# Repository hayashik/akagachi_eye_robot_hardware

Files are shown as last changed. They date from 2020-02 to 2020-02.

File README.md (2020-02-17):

# CAD data for DIY Akagachi
This data to develop your own Akagachi eye component.
3D printable data and 3D cad data are available. Software details are [here](https://github.com/hayashik/akagachi_eye_robot_ros).
There are follow two modes.  

## Akagachi type1 mode A
- Merit : Compact, easy to modify
- Demerit : Brush servo moters that connected directly will lower the robustness

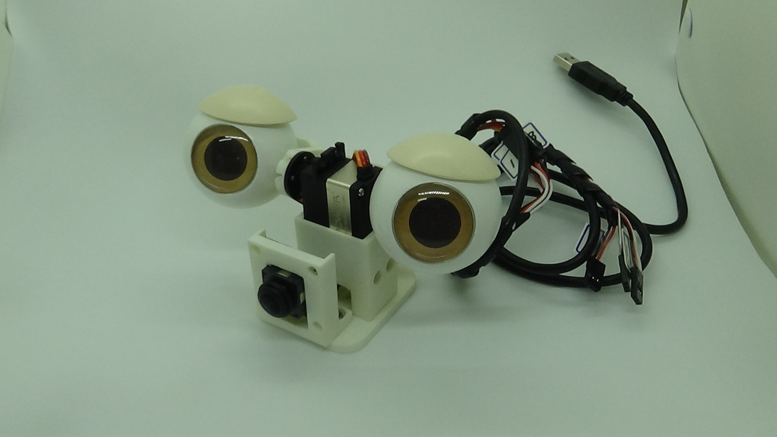
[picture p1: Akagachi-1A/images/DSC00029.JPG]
Overview1-A


## Akagachi type1 mode B
**2B is in preparation.**  
This data to develop your own Akagachi eye component.  
Type-1 is a small one (eye siza: 30mm) and a compact mode.
- Merit : Compact, easy to modify
- Demerit : Brushkess servo moters that connected by linkage will higher the robustness

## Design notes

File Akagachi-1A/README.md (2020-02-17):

CAD data for DIY Akagachi type1 mode A
====
## Overview  

This data to develop your own Akagachi eye component.  
Type-1 is a small one (eye siza: 30mm) and a compact mode.
- Merit : Compact, easy to modify
- Demerit : Brush servo moters that connected directly will lower the robustness
3D printable data and 3D cad data are available.

|Overviews||  
|:---|:---|
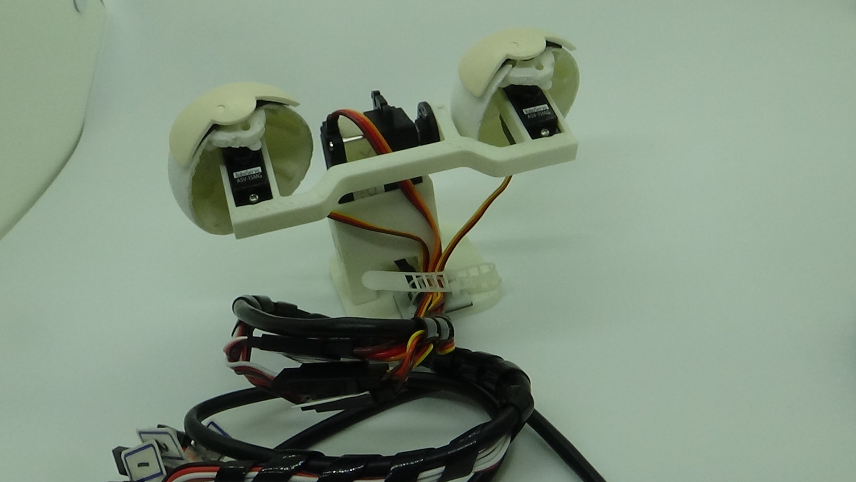
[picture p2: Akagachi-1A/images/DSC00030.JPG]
Back
|Overview||  
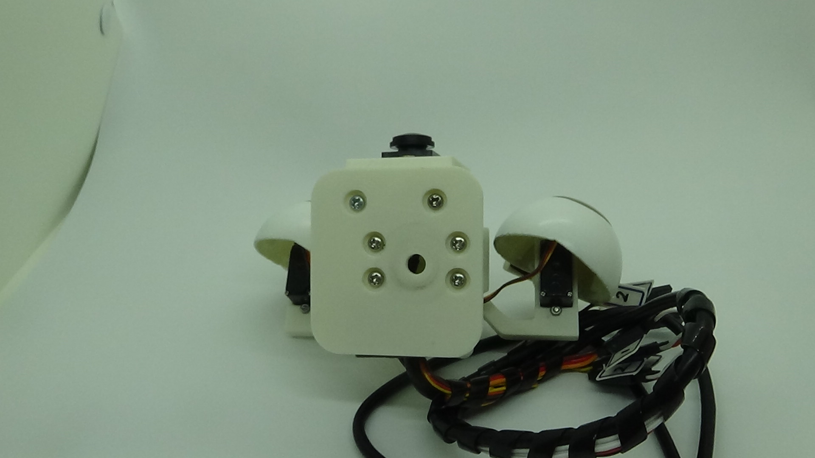
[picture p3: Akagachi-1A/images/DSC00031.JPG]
Bottom
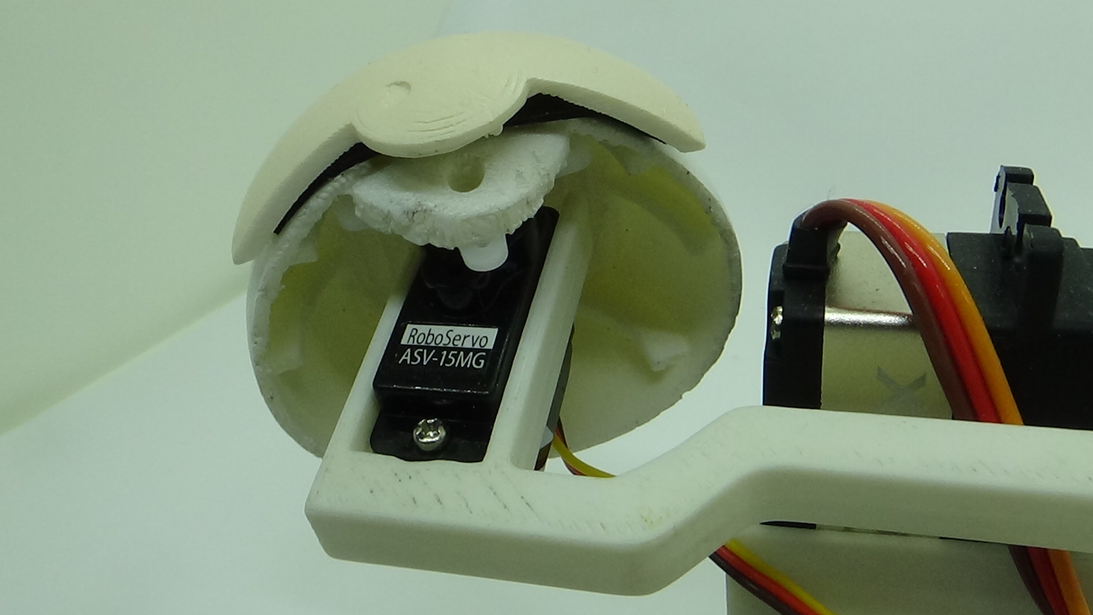
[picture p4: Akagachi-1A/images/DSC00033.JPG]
Yaw servo
|||  
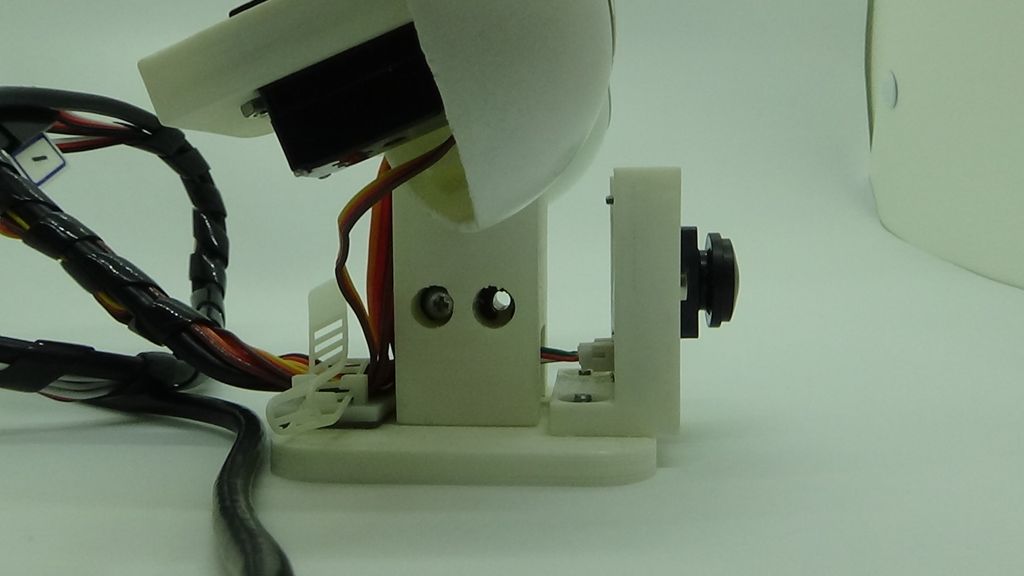
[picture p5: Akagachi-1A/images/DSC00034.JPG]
Side
|||  

## CAD data
We are assuming that these parts are 3D printed by the ABS or the Nylon.

|CAD name|Description|  
|:---|:---|
|Eyeball-ASV|Eyeball parts for ASV-15-MG. A Pupil needs to be colored by your hand.|  
|Eyeball-ASV-clear|Eyeball parts for ASV-15-MG. A Pupil needs to be put a seal. After that, a crea cabochon ([e.g.](https://www.amazon.co.jp/dp/B01N9BWMKV)) is applied.|  
|Eyeball-GWS pico|Eyeball parts for PIC/STD/F. A Pupil need to be colored by your hand.|  
|Eyelid|Apparent eyelid for eyeballs. Please attach it to one another.|  
|Yaw-bracket-GWS pico|Bracket of two eye servos (PIC/STD/F) mounts on the pitch servo (H1700HS-HV).|  
|Yaw-bracket-ASV|Bracket of two eye servos (ASV-15-MG) mounts on the pitch servo (XQ-S3008D).|  
|Pitch-servo-mt-thread-XQ|Stand for the pitch servo (XQ-S3008D). Please make thread holes!|  
|Pitch-servo-mt-thread-HV|Stand for the pitch servo (H1700HS-HV). Please make thread holes!|  
|1-A-CameraStand|Stand for all parts and joint to camera stands such as Tripods.|  
|1-A-CameraStand-GoogleHome|Stand for all parts and joint to the Google home.|  
|1-A-CameraStand-AmazonEcho|Stand for all parts and joint to the Amazon echo.|  
|CameraHold|Stand for USB camera (ELP usb camera).|  

## Parts list
Parts ever used (5V)  
If you can't get follow parts, choose a close performance one and remake CAD data.
I would really appreciate your sharing of new appropriate parts.

### Servos
|Servo|Manufacturer|Stall current<br>(mA)|No load speed<br>(sec/60°)|Torque<br>(kgf-cm)|description|  
|:---|:---|:---:|:---:|:---:|:---|
|PIC/STD/F|[GWS](https://gwsus.com/gws_com_tw_www/english/product/servo/sub%20micro.htm)||0.12|0.7|yaw servo|  
|ASV-15-MG|[Asakusa Gi Ken](http://www.robotsfx.com/robot/ASV-15.html)|300|0.125|1.6|yaw servo|  
|H1700HS-HV|[Blue Arrow](http://www.ltair.com/index.php?route=product/product&manufacturer_id=8&product_id=351)||0.068|2.7|pitch servo|  
|XQ-S3008D|[XQ Power](http://www.xq-power.com/XQ-S30P/show_64.html)|1750|0.09|7|pitch servo|  

### Other parts
|Parts name|Manufacturer|Description|  
|:---|:---|:---|
|ELP-USB500W02M-AF170|[ELP](hhttp://www.webcamerausb.com/elp-wide-angle-5megapixels-high-resolution-ov5640-sensor-module-pcb-mini-auto-focus-camera-usb-with-170degree-fisheye-lens-p-64.html)|In this ROS package, we used 640x480 resolution.|  
|M2 x 8||Yaw-bracket-xx is fixed to Pitch servo horn (4 screws). 2 yaw Servos are fixed to Yaw-bracket-xx (4 screws). CELP-camera is fixed to CameraHold (4 screws & 4 nuts). Servo horn and Yaw-bracket-xx are need to be threaded screw hole|
|M3 x 8||Pitch-servo-mt-xx (4 screws) and CameraHold (2 screws & nuts) are fixed to 1-A-CameraStand. Pitch-servo-mt-xx is need to be threaded 4 screw hole|
|M3 x 15||Pitch servo is fixed to Pitch-servo-mt-xx (2 screws). Pitch-servo-mt-xx is need to be threaded 2 screw hole|

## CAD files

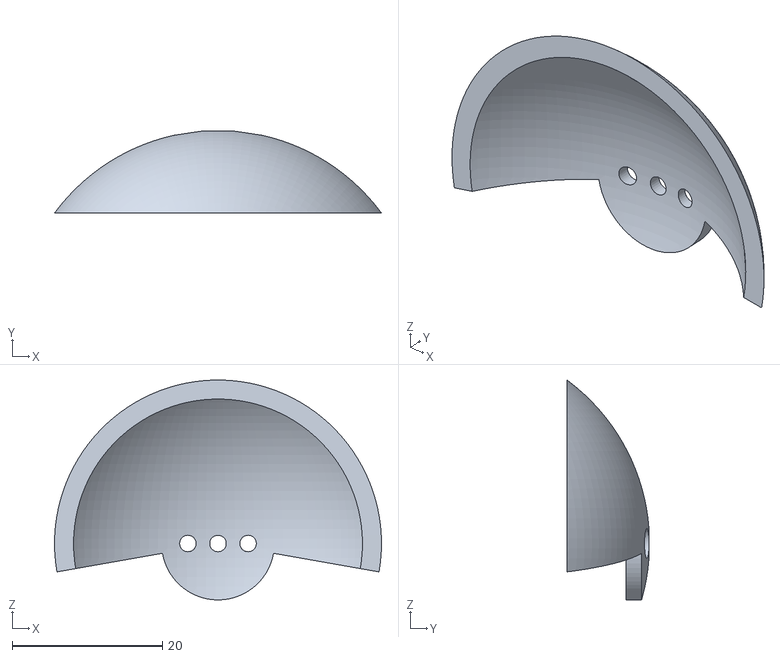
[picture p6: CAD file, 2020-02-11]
Akagachi-1A/Eyelid.stl
43.5 x 10.9 x 29.2

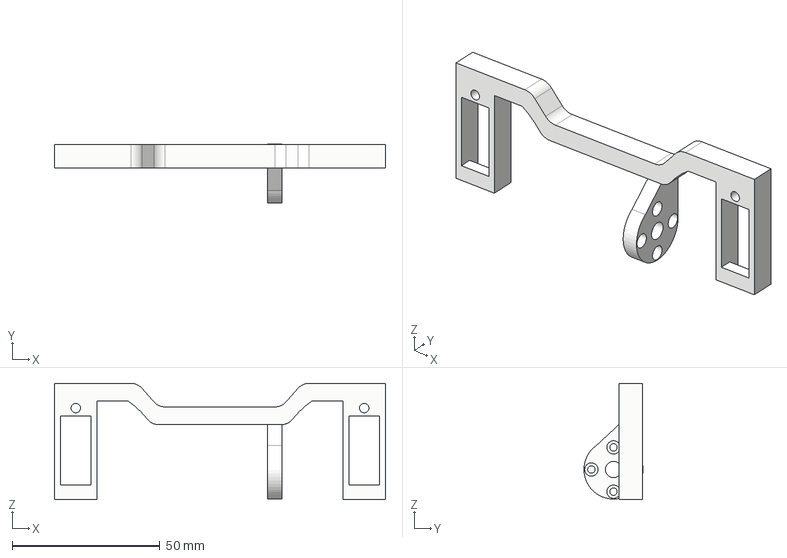
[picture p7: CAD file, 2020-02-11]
Akagachi-1A/Yaw-bracket-GWS pico.step
112.0 x 20.0 x 39.4 mm

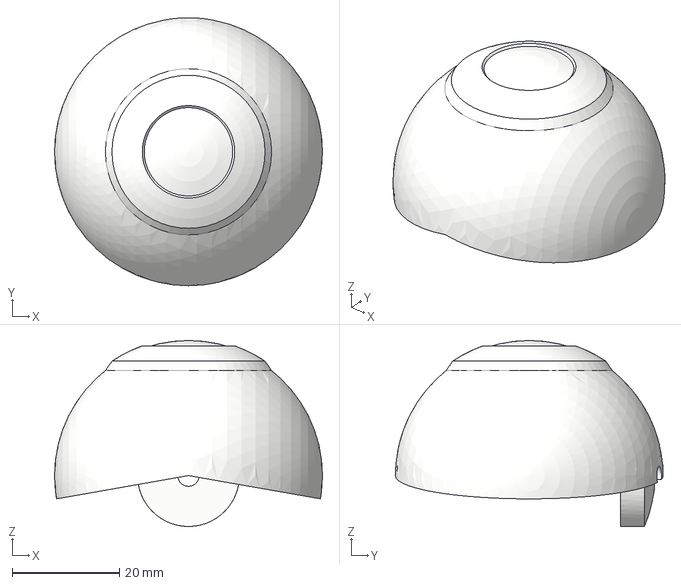
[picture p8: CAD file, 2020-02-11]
Akagachi-1A/Eyeball-GWS pico.step
50.0 x 49.9 x 34.7 mm

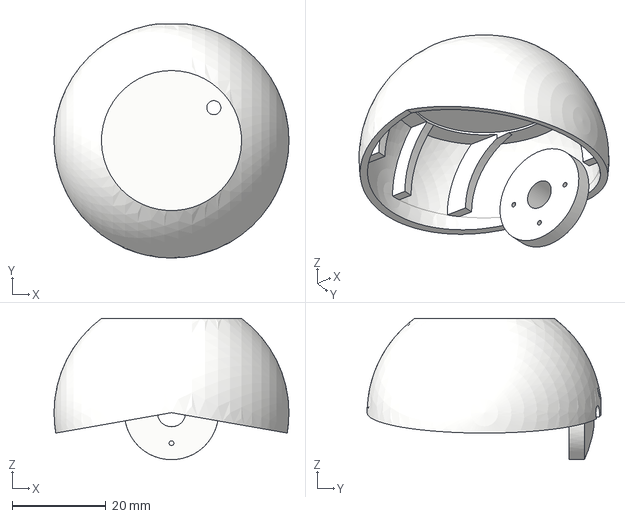
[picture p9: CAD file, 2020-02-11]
Akagachi-1A/Eyeball-ASV-clear.step
50.0 x 49.8 x 30.1 mm

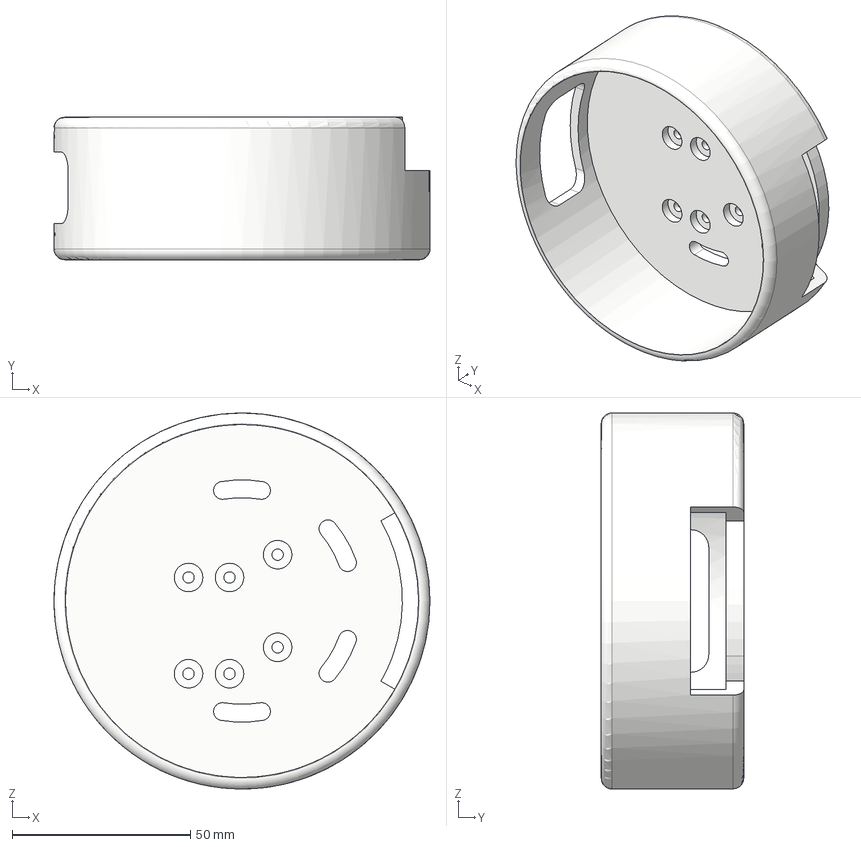
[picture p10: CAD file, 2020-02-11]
Akagachi-1A/1-A-CameraStand-AmazonEcho.step
105.5 x 40.0 x 105.5 mm

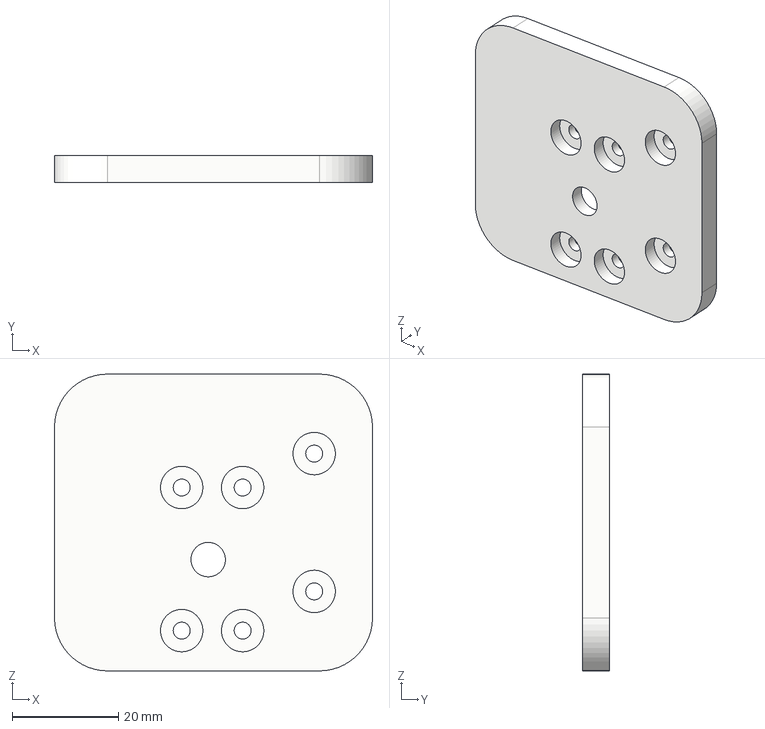
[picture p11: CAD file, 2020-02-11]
Akagachi-1A/1-A-CameraStand.step
60.0 x 5.00 x 56.0 mm

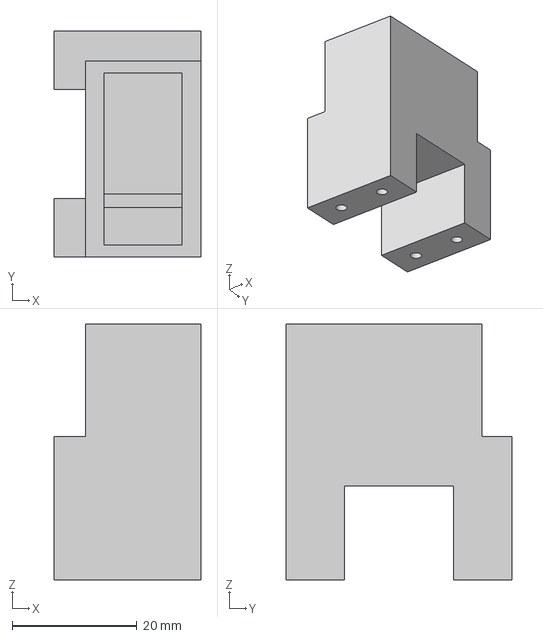
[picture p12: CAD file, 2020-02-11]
Akagachi-1A/Pitch-servo-mt-thread-HV.step
23.5 x 36.2 x 41.0 mm

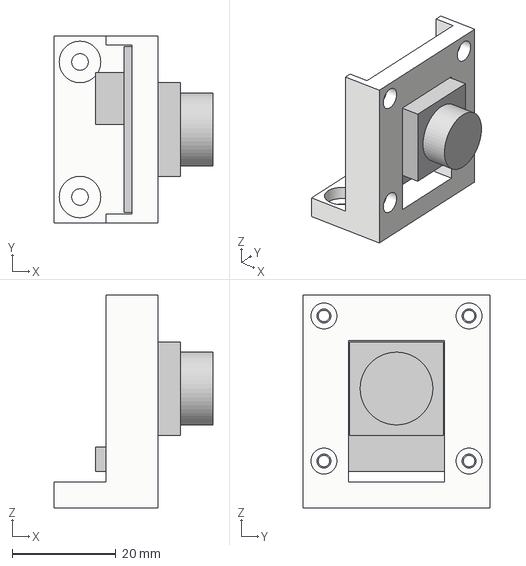
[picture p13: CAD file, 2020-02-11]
Akagachi-1A/CameraHold.step
30.6 x 36.0 x 41.0 mm

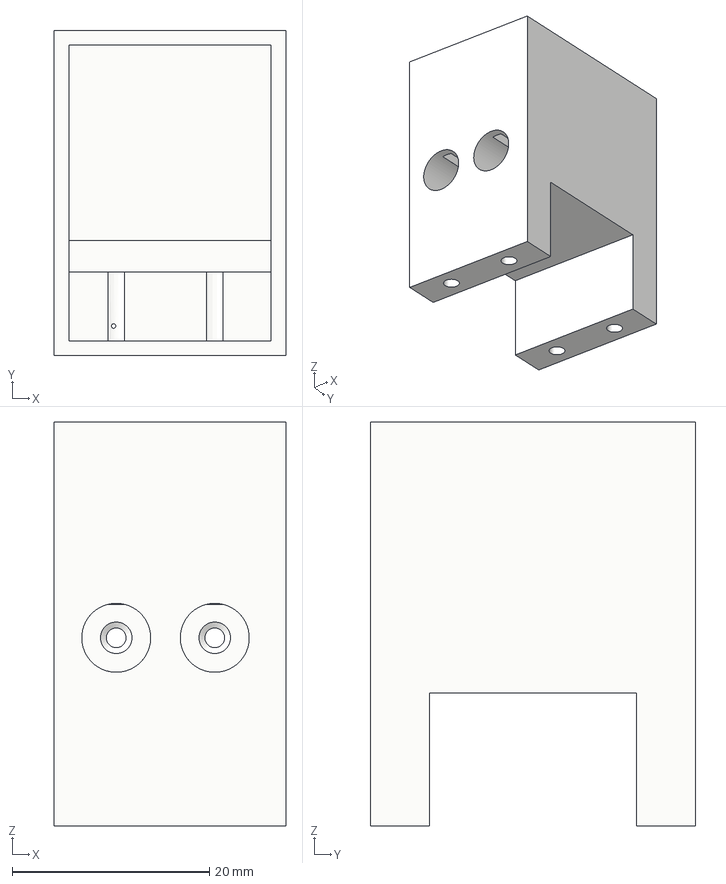
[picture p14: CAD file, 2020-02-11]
Akagachi-1A/Pitch-servo-mt-thread-XQ.step
23.5 x 33.0 x 41.0 mm

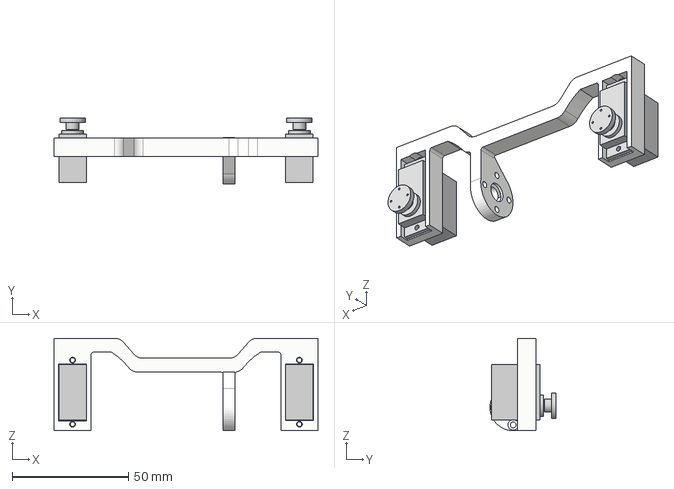
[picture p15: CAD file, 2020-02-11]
Akagachi-1A/Yaw-bracket-ASV.step
113.6 x 28.4 x 39.8 mm
servo x 2
horn x 2

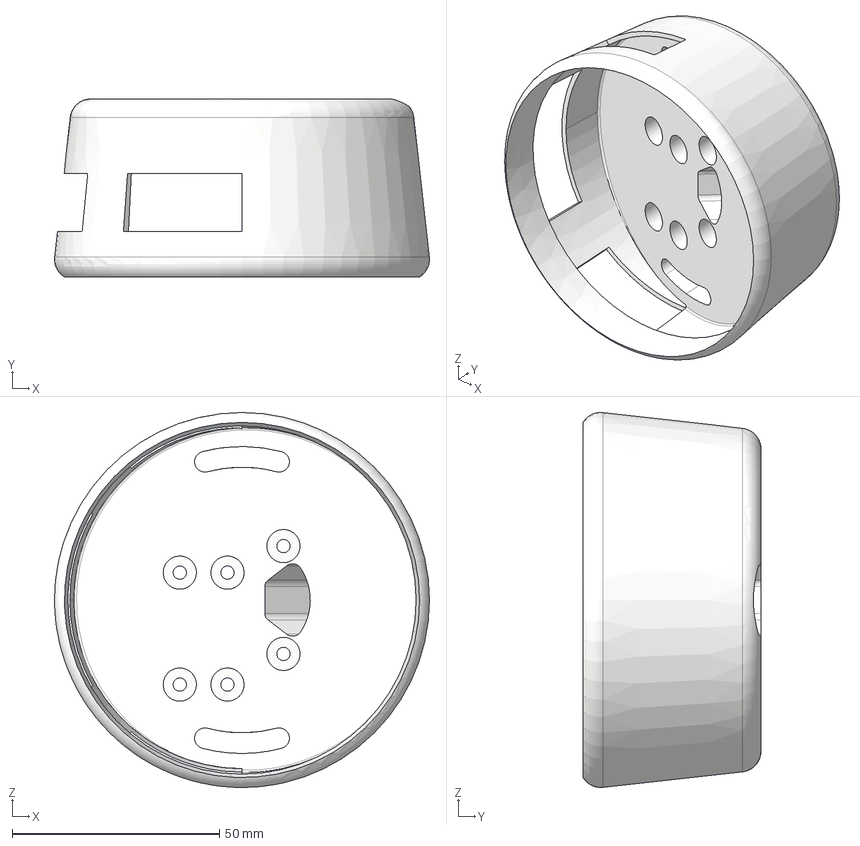
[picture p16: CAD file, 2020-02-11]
Akagachi-1A/1-A-CameraStand-GoogleHome.step
90.4 x 42.9 x 90.4 mm

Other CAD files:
Akagachi-1A/Eyeball-ASV.step
Akagachi-1A/1-A-CameraStand-AmazonEcho.stl
Akagachi-1A/1-A-CameraStand-GoogleHome.stl
Akagachi-1A/1-A-CameraStand.stl
Akagachi-1A/CameraHold.stl
Akagachi-1A/Eyeball-ASV-clear.stl
Akagachi-1A/Eyeball-ASV.stl
Akagachi-1A/Eyeball-GWS pico.stl
Akagachi-1A/Pitch-servo-mt-thread-HV.stl
Akagachi-1A/Pitch-servo-mt-thread-XQ.stl
Akagachi-1A/Yaw-bracket-ASV.stl
Akagachi-1A/Yaw-bracket-GWS pico.stl
